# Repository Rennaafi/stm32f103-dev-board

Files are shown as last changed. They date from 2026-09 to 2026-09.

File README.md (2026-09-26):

# STM32F103 Minimal Development Board

A compact 2-layer STM32F103 (LQFP-48) breakout board designed in **KiCad 9**. It is powered over USB and exposes SWD, SPI and I2C on pin headers.

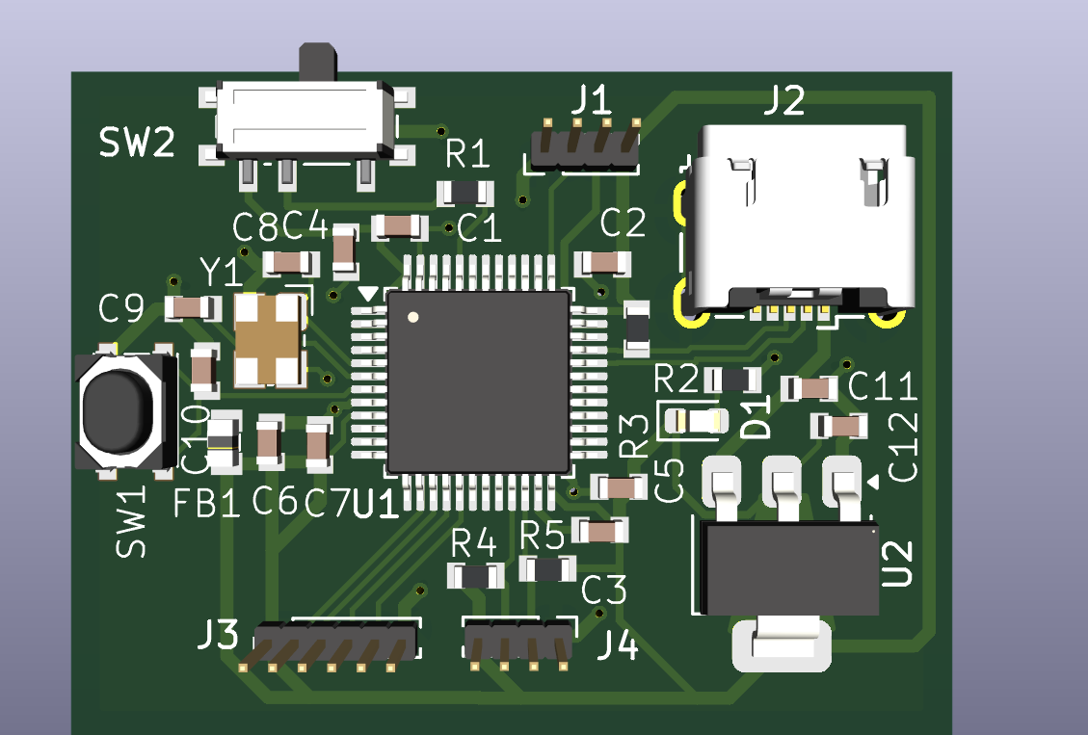
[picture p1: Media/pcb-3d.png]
3D render


## Features

- **MCU:** STM32F103 in LQFP-48 (U1)
- **Clock:** 16 MHz crystal (TSX-3225) with 8 pF load capacitors
- **Power:** USB Micro-B → AMS1117-3.3 LDO → 3.3 V, with a ferrite bead (120 Ω) filtering VDDA
- **USB:** D+ pull-up (1k5) on PA12
- **Boot mode:** slide switch (SW2) on BOOT0
- **Reset:** tactile button (SW1) on NRST
- **Power LED:** red LED (D1)
- **Headers:**
  - `J1`: SWD (3V3, SWDIO, SWCLK, GND)
  - `J3`: SPI1 (3V3, NSS, SCK, MISO, MOSI, GND)
  - `J4`: I2C1 on PB10/PB11 with 1k5 pull-ups
- **Board:** about 33.5 × 24.2 mm, 2 layers, 1.6 mm thick, all components on the top side

## Schematic

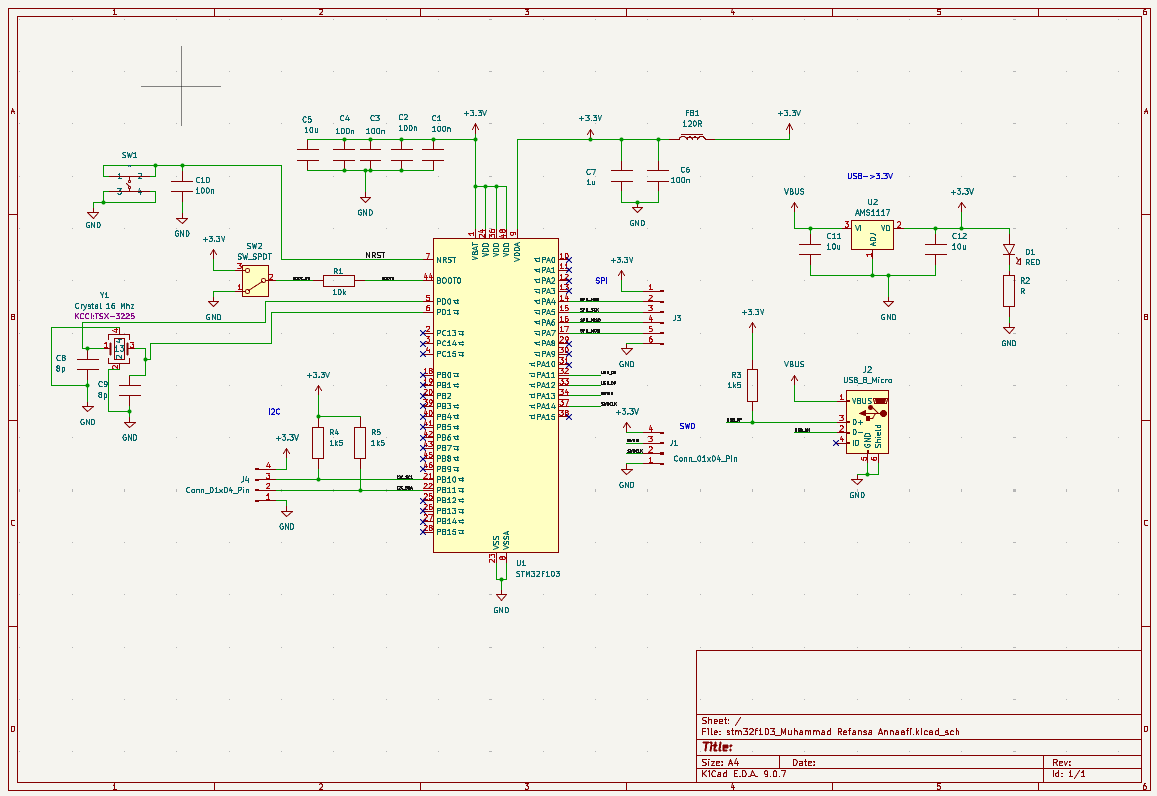
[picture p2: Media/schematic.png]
Schematic


## PCB Layout

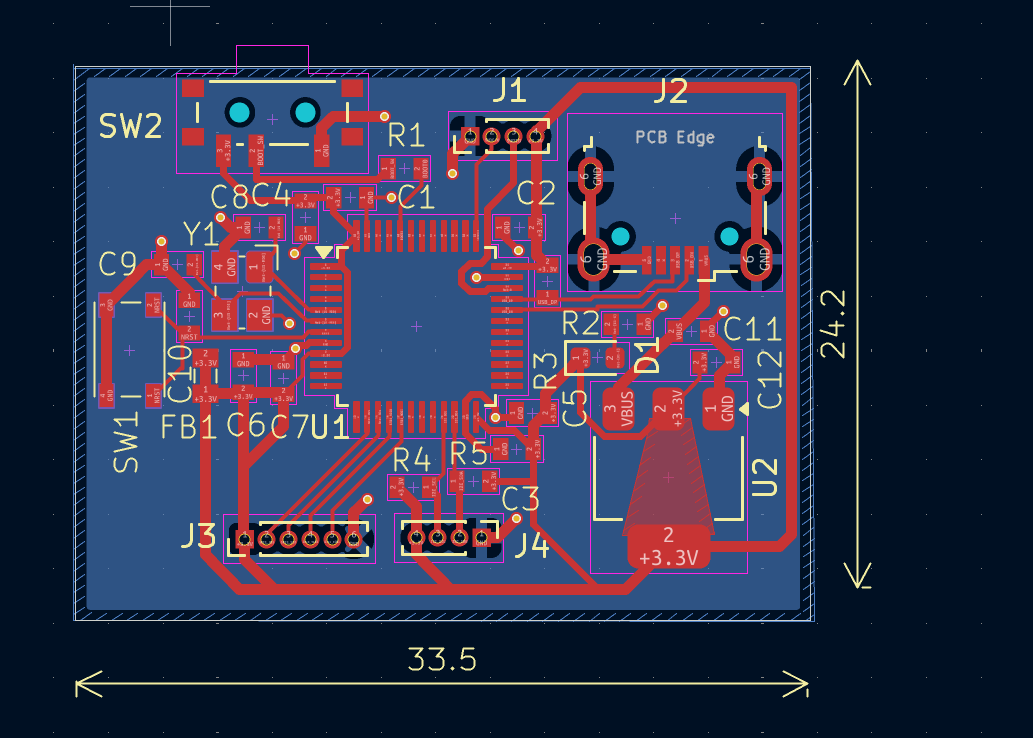
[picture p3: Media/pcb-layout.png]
PCB layout


## Repository Structure

```
.
├── stm32f103_Muhammad Refansa Annaafi.kicad_pro   # KiCad project
├── stm32f103_Muhammad Refansa Annaafi.kicad_sch   # Schematic
├── stm32f103_Muhammad Refansa Annaafi.kicad_pcb   # PCB layout
├── Gerber/    # Fabrication outputs (Gerbers, drill files, job file)
├── BOM/       # Bill of materials (CSV)
└── Media/     # Screenshots and renders
```

## Bill of Materials

| Ref | Value | Footprint | Qty |
|---|---|---|---|
| U1 | STM32F103 | LQFP-48_7x7mm_P0.5mm | 1 |
| U2 | AMS1117-3.3 | SOT-223-3 | 1 |
| Y1 | 16 MHz crystal | TSX-3225 | 1 |
| J2 | USB Micro-B | Würth 629105150521 | 1 |
| FB1 | 120 Ω ferrite bead | BLM18PG121SN1D (0603) | 1 |
| C1–C4, C6, C10 | 100 nF | 0603 | 6 |
| C5, C11, C12 | 10 µF | 0603 | 3 |
| C7 | 1 µF | 0603 | 1 |
| C8, C9 | 8 pF | 0603 | 2 |
| R1 | 10 kΩ | 0603 | 1 |
| R3, R4, R5 | 1.5 kΩ | 0603 | 3 |
| R2 | 1 kΩ (LED resistor) | 0603 | 1 |
| D1 | Red LED | 0603 | 1 |
| SW1 | Tactile switch | 434133025816 | 1 |
| SW2 | SPDT slide switch | PCM12 | 1 |
| J1, J4 | 1×4 header | 1.00 mm pitch | 2 |
| J3 | 1×6 header | 1.00 mm pitch | 1 |

The full BOM is in [`BOM/`](BOM).

## Manufacturing

Upload the contents of [`Gerber/`](Gerber) to a PCB fab such as JLCPCB or PCBWay. It includes the copper, mask, paste, silkscreen and edge-cut layers, plus the PTH/NPTH drill files.

## Opening the Project

Open the `.kicad_pro` file in KiCad 9.0 or newer. The project uses a custom `KCCI` symbol/footprint library for some parts (for example the crystal). If those parts show up as missing, add that library to your library tables.

## Author

Muhammad Refansa Annaafi. Designed as part of the KCCI PCB design training.

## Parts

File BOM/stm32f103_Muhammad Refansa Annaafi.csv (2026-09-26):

Id | Designator | Footprint | Quantity | Designation | Supplier and ref
1 | U2 | SOT-223-3_TabPin2 | 1 | AMS1117
2 | C7 | C_0603_ | 1 | 1u
3 | SW1 | button_434133025816 | 1 | ~
4 | C8,C9 | C_0603_ | 2 | 8p
5 | R1 | R_0603 | 1 | 10k
6 | R5,R3,R4 | R_0603 | 3 | 1k5
7 | C1,C3,C10,C4,C2,C6 | C_0603_ | 6 | 100n
8 | Y1 | TSX-3225 | 1 | Crystal 16 Mhz
9 | J1,J4 | PinHeader_1x04_P1.00mm_Vertical | 2 | Conn_01x04_Pin
10 | C12,C11,C5 | C_0603_ | 3 | 10u
11 | SW2 | SW_SPDT_PCM12 | 1 | SW_SPDT
12 | U1 | LQFP-48_7x7mm_P0.5mm | 1 | STM32F103
13 | FB1 | BLM18PG121SN1D | 1 | 120R
14 | R2 | R_0603 | 1 | 1k
15 | J3 | PinHeader_1x06_P1.00mm_Vertical | 1 | Conn_01x06_Pin
16 | J2 | USB_Micro-B_Wuerth_629105150521 | 1 | USB_B_Micro
17 | D1 | LED_0603_1608Metric | 1 | RED

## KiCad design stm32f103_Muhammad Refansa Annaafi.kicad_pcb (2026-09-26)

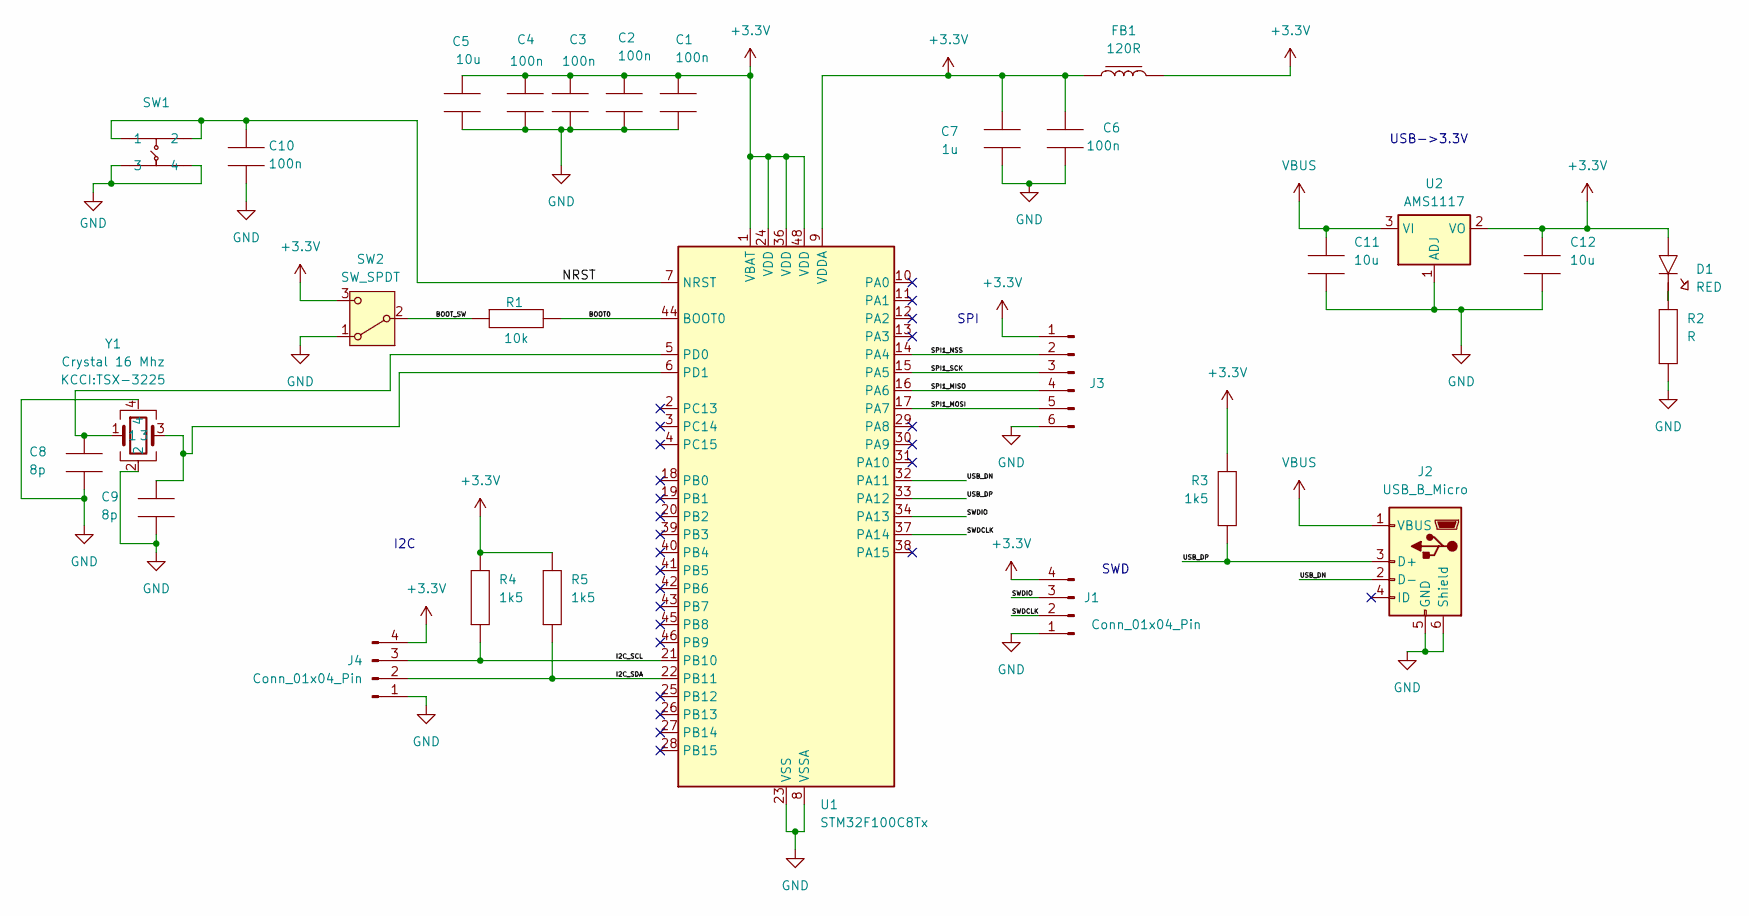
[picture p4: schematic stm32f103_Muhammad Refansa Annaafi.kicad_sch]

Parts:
C1, C2, C3, C4, C6, C10: 100n; C_0603_
C5, C11, C12: 10u; C_0603_
C7: 1u; C_0603_
C8, C9: 8p; C_0603_
D1: RED; LED_0603_1608Metric
FB1: 120R; BLM18PG121SN1D
J1, J4: Conn_01x04_Pin; PinHeader_1x04_P1.00mm_Vertical
J2: USB_B_Micro; USB_Micro-B_Wuerth_629105150521
J3: Conn_01x06_Pin; PinHeader_1x06_P1.00mm_Vertical
R1: 10k; R_0603
R2: R; R_0603
R3, R4, R5: 1k5; R_0603
SW1: button_434133025816
SW2: SW_SPDT; SW_SPDT_PCM12
U1: STM32F100C8Tx; LQFP-48_7x7mm_P0.5mm
U2: AMS1117; SOT-223-3_TabPin2
Y1: Crystal 16 Mhz; TSX-3225

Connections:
+3.3V: C1.2, C2.2, C3.2, C4.2, C5.2, C6.2, C7.2, C12.2, D1.1 (A), FB1.1, FB1.2, J1.4, J3.1, J4.4, R3.2, R4.2, R5.2, SW2.3 (C), U1.1 (VBAT), U1.9 (VDDA), U1.24 (VDD), U1.36 (VDD), U1.48 (VDD), U2.2 (VO)
/BOOT0: R1.2, U1.44 (BOOT0)
/BOOT_SW: R1.1, SW2.2 (B)
/I2C_SCL: J4.3, R4.1, U1.21 (PB10)
/I2C_SDA: J4.2, R5.1, U1.22 (PB11)
/NRST: C10.2, SW1.1, SW1.2, U1.7 (NRST)
/SPI1_MISO: J3.4, U1.16 (PA6)
/SPI1_MOSI: J3.5, U1.17 (PA7)
/SPI1_NSS: J3.2, U1.14 (PA4)
/SPI1_SCK: J3.3, U1.15 (PA5)
/SWDCLK: J1.2, U1.37 (PA14)
/SWDIO: J1.3, U1.34 (PA13)
/USB_DN: J2.2 (D-), U1.32 (PA11)
/USB_DP: J2.3 (D+), R3.1, U1.33 (PA12)
GND: C1.1, C2.1, C3.1, C4.1, C5.1, C6.1, C7.1, C8.1, C9.1, C10.1, C11.1, C12.1, J1.1, J2.5 (GND), J2.6 (Shield), J3.6, J4.1, R2.1, SW1.3, SW1.4, SW2.1 (A), U1.8 (VSSA), U1.23 (VSS), U1.35 (VSS), U1.47 (VSS), U2.1 (ADJ), Y1.2, Y1.4
unnamed: D1.2 (C), R2.2
unnamed: C8.2, U1.5 (PD0), Y1.1
unnamed: C9.2, U1.6 (PD1), Y1.3
VBUS: C11.2, J2.1 (VBUS), U2.3 (VI)

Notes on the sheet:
SPI
I2C
USB->3.3V
SWD

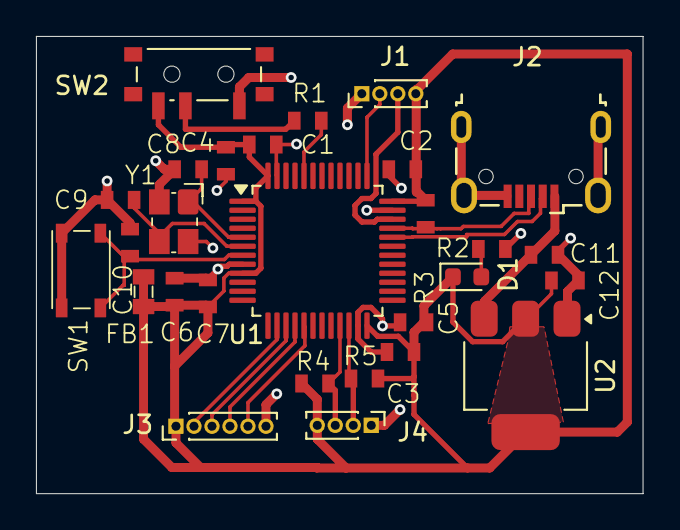
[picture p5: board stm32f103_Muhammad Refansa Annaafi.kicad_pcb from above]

Board: 2 copper layers, 33.7 x 25.4 mm, 28 parts (0 on the bottom side), 19 nets.

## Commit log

2026-09-26 Initial commit: STM32F103 dev board KiCad project
    Schematic, PCB layout, Gerber/drill outputs, BOM, and README with renders.
    [stm32f103_Muhammad Refansa Annaafi-B_Cu.gbr, stm32f103_Muhammad Refansa Annaafi-B_Mask.gbr, stm32f103_Muhammad Refansa Annaafi-B_Paste.gbr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]
2026-09-26 Rename MCU to STM32F103 and set R2 to 1k
    Update schematic, BOM, README, and schematic screenshot.
    [stm32f103_Muhammad Refansa Annaafi.csv, stm32f103_Muhammad Refansa Annaafi.kicad_sch]
